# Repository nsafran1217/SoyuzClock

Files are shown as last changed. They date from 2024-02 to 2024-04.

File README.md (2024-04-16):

# SoyuzClock
Recreation of the 744H clock that flew on Soyuz space capsules

This is meant to be an accurate replica of the Soyuz 744H clock as feature on CuriousMarc's youtube channel.

- `SoyuzControlBoard` contains the KiCAD files for the esp32 board. There are many components that are optional.

- `SoyuzLedBoard` contains the KiCAD files for the board that the LED display mount on.

- `Soyuz-esp32` contains the PlatformIO project that runs the clock

## Part numbers
- АЛС324А is the 7 segment LED display. They are available on eBay or at tubes-store.com. They have the same quality issues as found in the real clock.

- МТ-1 is the toggle switch. They are available on eBay.

- ПКн2-1 is the correct push button, however, they are hard to find in the west. I found some stores selling them in Ukraine and Russia, but each switch is at least $15 US, plus you need to convince the seller its worth their time to ship it to you.

- KM1-1 is the next best option. They are easily found on eBay. The push button is smaller than the real switch. This is what I am using for now.

# 
Thanks to Curious Marc for documenting this clock: https://www.curiousmarc.com/space/soyuz-clock-744h-digital

I made a recreation of the case in FreeCAD based HEAVILY on this FreeCAD design: https://grabcad.com/library/soyuz-spacecraft-clock-1

This design will be added to this repo when finalized.

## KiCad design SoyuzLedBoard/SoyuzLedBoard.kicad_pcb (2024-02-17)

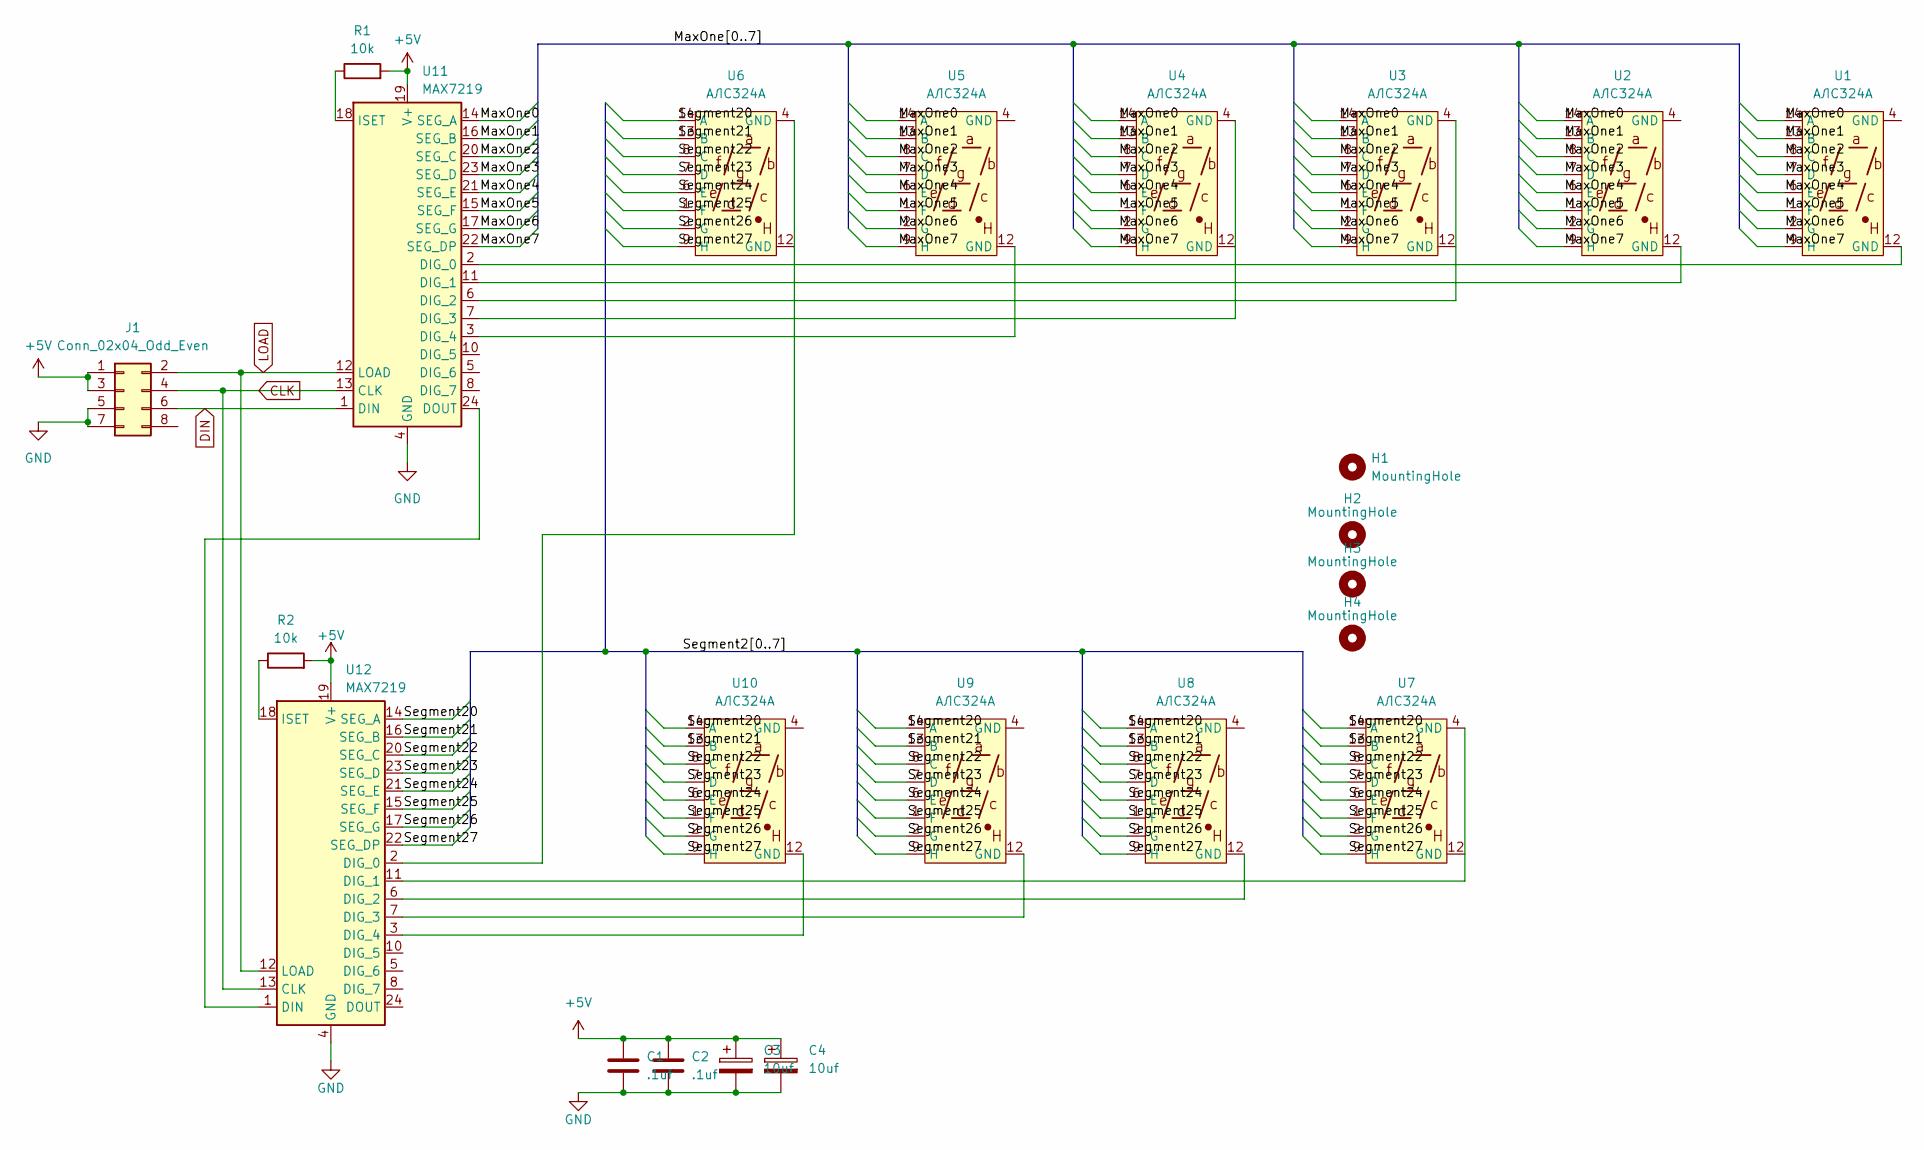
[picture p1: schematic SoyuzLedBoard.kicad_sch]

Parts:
C1, C2: .1uf; C_0805_2012Metric_Pad1.18x1.45mm_HandSolder
C3, C4: 10uf; CP_Radial_D4.0mm_P2.00mm
H1, H2, H3, H4: MountingHole; MountingHole_3.2mm_M3
J1: Conn_02x04_Odd_Even; PinHeader_2x04_P2.54mm_Vertical
R1, R2: 10k; R_0805_2012Metric_Pad1.20x1.40mm_HandSolder
U1, U2, U3, U4, U5, U6, U7, U8, U9, U10: АЛС324А; Metric-2.5mm DIP14
U11, U12: MAX7219; DIP-24_W7.62mm

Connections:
+5V: C1.1, C2.1, C3.1, C4.1, J1.1, J1.3, R1.2, R2.2, U11.19 (V+), U12.19 (V+)
/MaxOne0: U1.14 (A), U2.14 (A), U3.14 (A), U4.14 (A), U5.14 (A), U11.14 (SEG_A)
/MaxOne1: U1.13 (B), U2.13 (B), U3.13 (B), U4.13 (B), U5.13 (B), U11.16 (SEG_B)
/MaxOne2: U1.8 (C), U2.8 (C), U3.8 (C), U4.8 (C), U5.8 (C), U11.20 (SEG_C)
/MaxOne3: U1.7 (D), U2.7 (D), U3.7 (D), U4.7 (D), U5.7 (D), U11.23 (SEG_D)
/MaxOne4: U1.6 (E), U2.6 (E), U3.6 (E), U4.6 (E), U5.6 (E), U11.21 (SEG_E)
/MaxOne5: U1.1 (F), U2.1 (F), U3.1 (F), U4.1 (F), U5.1 (F), U11.15 (SEG_F)
/MaxOne6: U1.2 (G), U2.2 (G), U3.2 (G), U4.2 (G), U5.2 (G), U11.17 (SEG_G)
/MaxOne7: U1.9 (H), U2.9 (H), U3.9 (H), U4.9 (H), U5.9 (H), U11.22 (SEG_DP)
/Segment20: U6.14 (A), U7.14 (A), U8.14 (A), U9.14 (A), U10.14 (A), U12.14 (SEG_A)
/Segment21: U6.13 (B), U7.13 (B), U8.13 (B), U9.13 (B), U10.13 (B), U12.16 (SEG_B)
/Segment22: U6.8 (C), U7.8 (C), U8.8 (C), U9.8 (C), U10.8 (C), U12.20 (SEG_C)
/Segment23: U6.7 (D), U7.7 (D), U8.7 (D), U9.7 (D), U10.7 (D), U12.23 (SEG_D)
/Segment24: U6.6 (E), U7.6 (E), U8.6 (E), U9.6 (E), U10.6 (E), U12.21 (SEG_E)
/Segment25: U6.1 (F), U7.1 (F), U8.1 (F), U9.1 (F), U10.1 (F), U12.15 (SEG_F)
/Segment26: U6.2 (G), U7.2 (G), U8.2 (G), U9.2 (G), U10.2 (G), U12.17 (SEG_G)
/Segment27: U6.9 (H), U7.9 (H), U8.9 (H), U9.9 (H), U10.9 (H), U12.22 (SEG_DP)
CLK: J1.4, U11.13 (CLK), U12.13 (CLK)
DIN: J1.6, U11.1 (DIN)
GND: C1.2, C2.2, C3.2, C4.2, J1.5, J1.7, U11.4 (GND), U11.9 (GND), U12.4 (GND), U12.9 (GND)
LOAD: J1.2, U11.12 (LOAD), U12.12 (LOAD)
unnamed: U1.12 (GND), U11.2 (DIG_0)
unnamed: U2.12 (GND), U11.11 (DIG_1)
unnamed: U3.4 (GND), U11.6 (DIG_2)
unnamed: U4.4 (GND), U11.7 (DIG_3)
unnamed: U5.12 (GND), U11.3 (DIG_4)
unnamed: U11.24 (DOUT), U12.1 (DIN)
unnamed: R1.1, U11.18 (ISET)
unnamed: U6.4 (GND), U12.2 (DIG_0)
unnamed: U7.4 (GND), U12.11 (DIG_1)
unnamed: U8.12 (GND), U12.6 (DIG_2)
unnamed: U9.12 (GND), U12.7 (DIG_3)
unnamed: U10.12 (GND), U12.3 (DIG_4)
unnamed: R2.1, U12.18 (ISET)

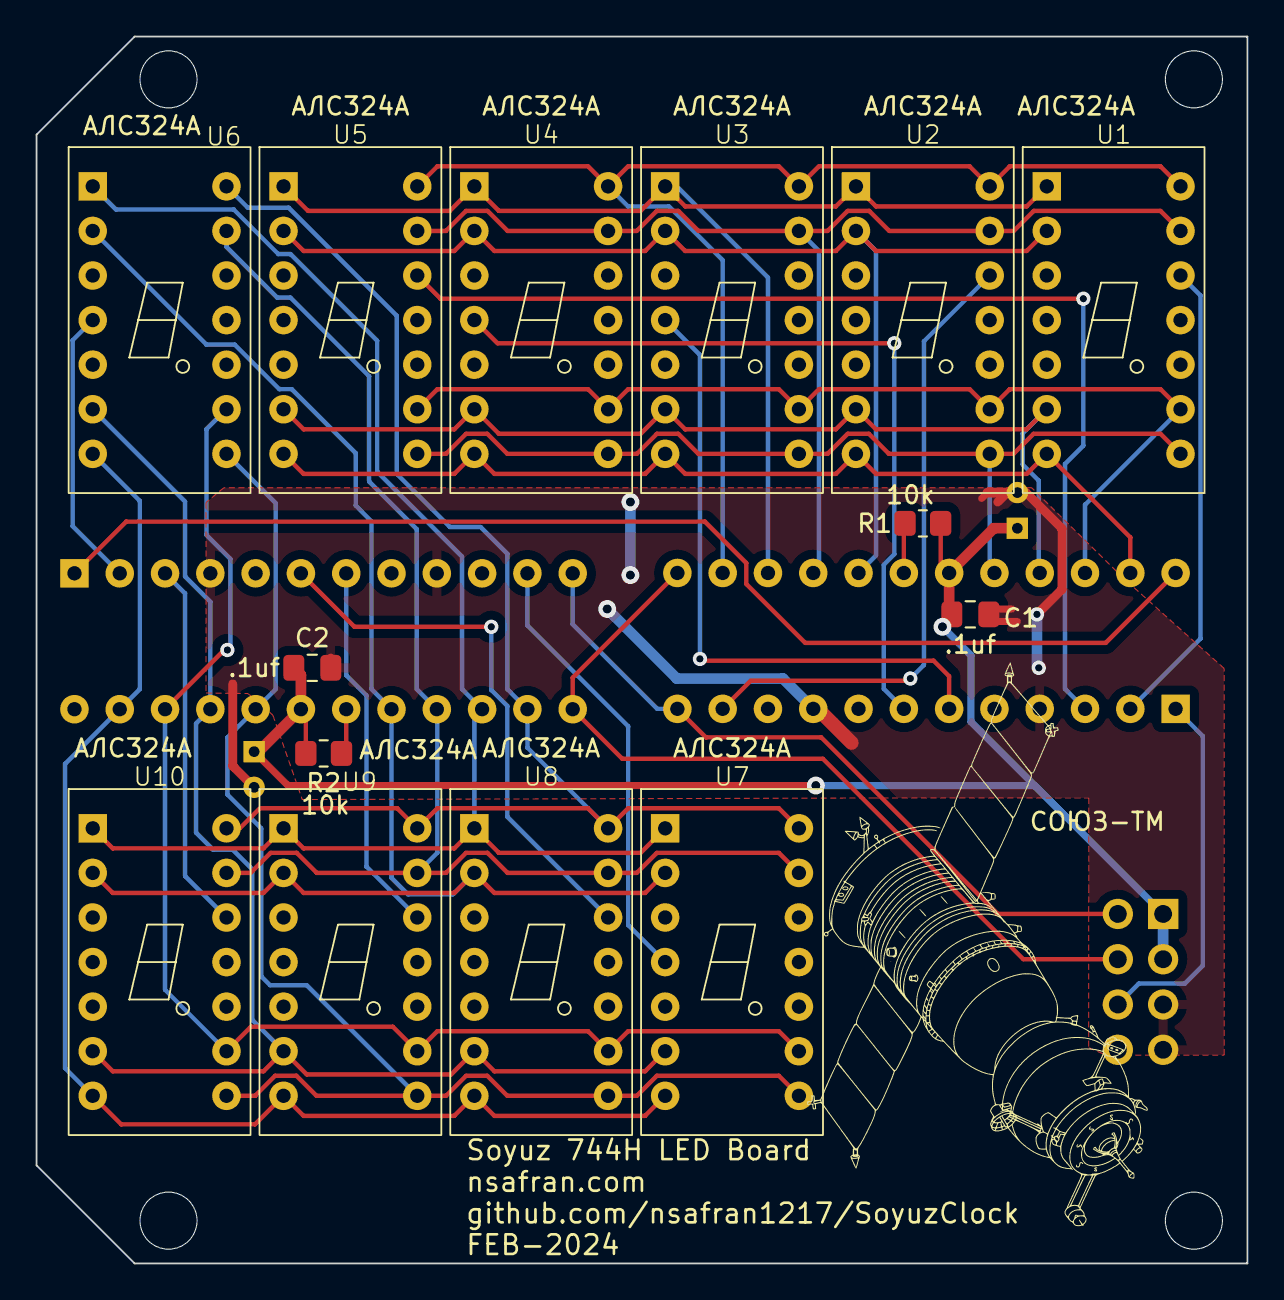
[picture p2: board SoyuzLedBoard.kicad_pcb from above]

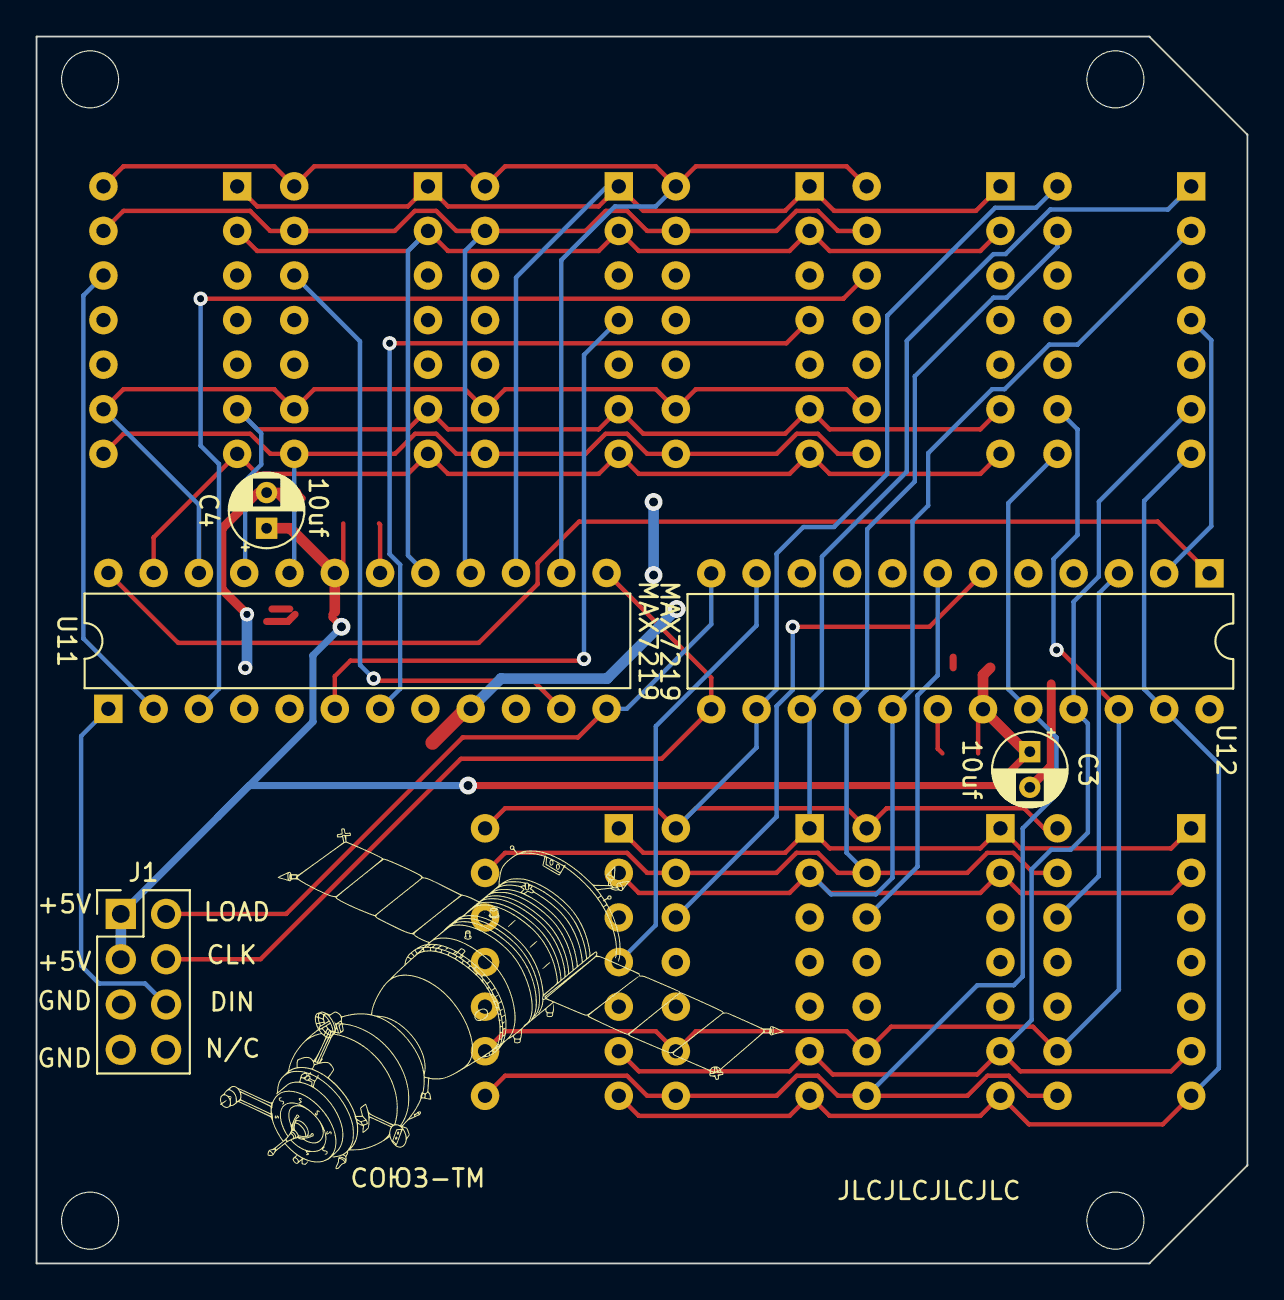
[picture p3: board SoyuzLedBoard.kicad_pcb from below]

Board: 2 copper layers, 67.9 x 68.8 mm, 23 parts (5 on the bottom side), 34 nets.

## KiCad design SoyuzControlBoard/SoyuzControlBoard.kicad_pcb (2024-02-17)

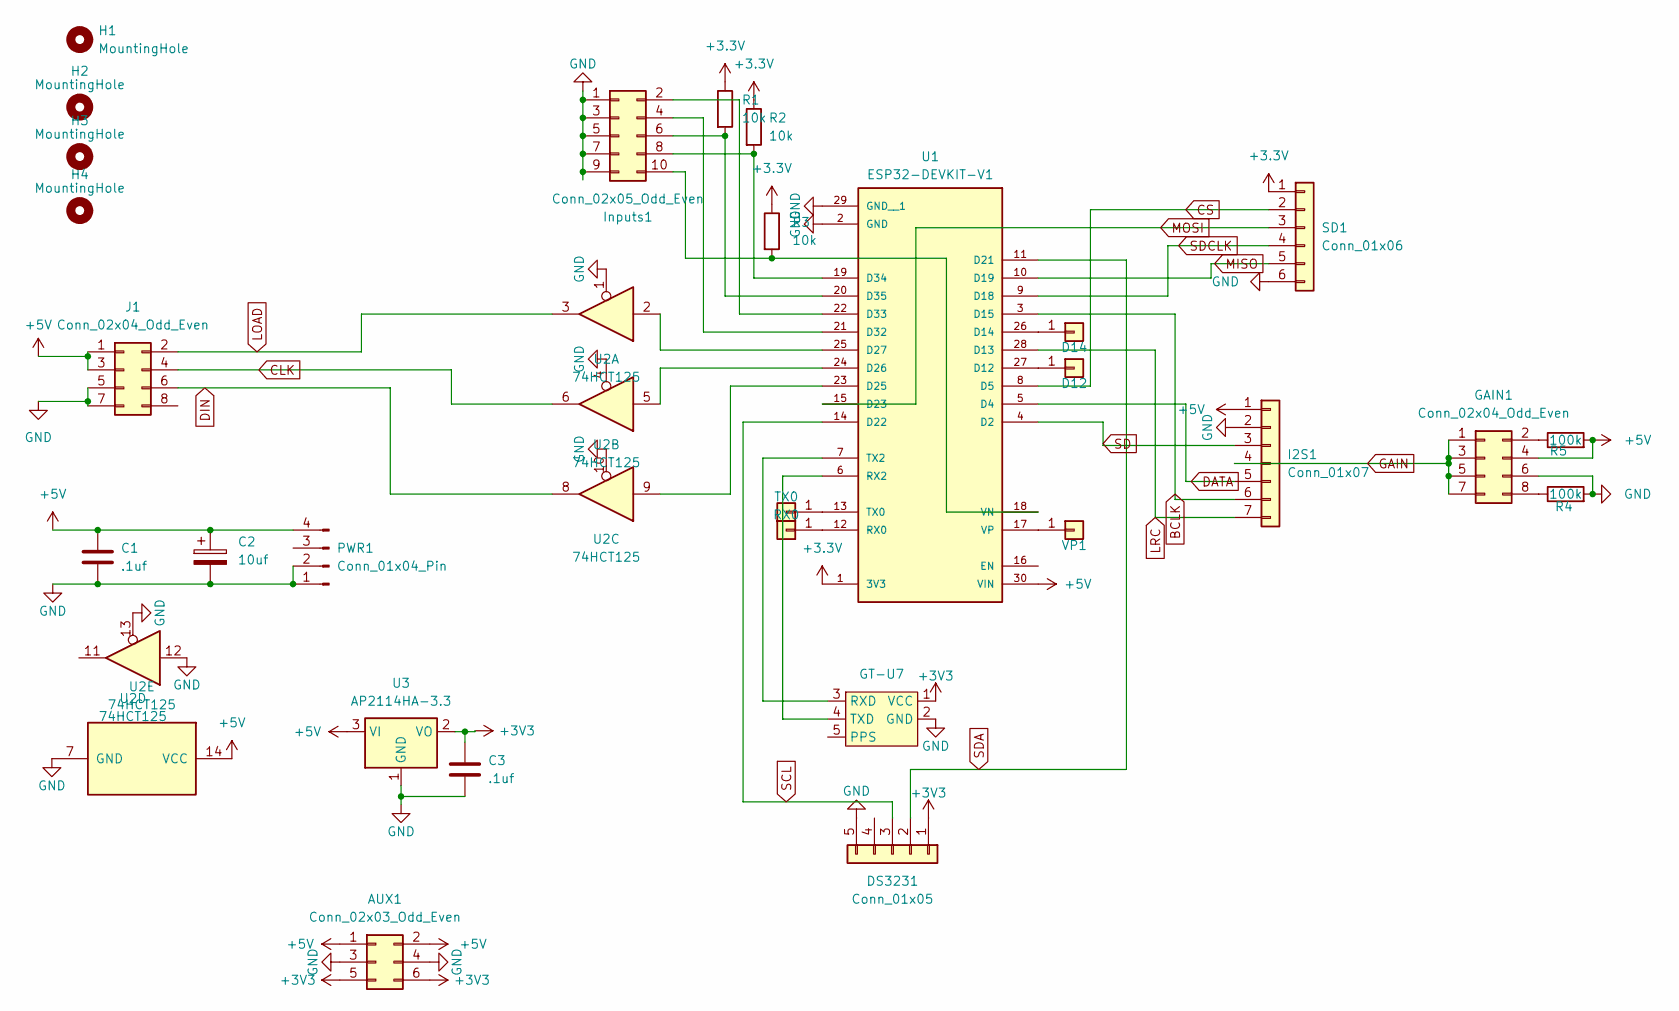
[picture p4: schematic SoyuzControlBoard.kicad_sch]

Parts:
AUX1: Conn_02x03_Odd_Even; PinHeader_2x03_P2.54mm_Vertical
C1, C3: .1uf; C_0805_2012Metric_Pad1.18x1.45mm_HandSolder
C2: 10uf; CP_Radial_D4.0mm_P2.00mm
D12, D14: Conn_01x01; 1x01
DS3231: Conn_01x05; PinHeader_1x05_P2.54mm_Vertical
GAIN1: Conn_02x04_Odd_Even; PinHeader_2x04_P2.54mm_Vertical
GT-U7: GT-U7_GPS
H1, H2, H3, H4: MountingHole; MountingHole_3.2mm_M3
I2S1: Conn_01x07; PinHeader_1x07_P2.54mm_Vertical
Inputs1: Conn_02x05_Odd_Even; IDC-Header_2x05_P2.54mm_Vertical
J1: Conn_02x04_Odd_Even; PinSocket_2x04_P2.54mm_Vertical
PWR1: Conn_01x04_Pin; PinHeader_1x04_P2.54mm_Vertical
R1, R2, R3: 10k; R_0805_2012Metric_Pad1.20x1.40mm_HandSolder
R4, R5: 100k; R_0805_2012Metric_Pad1.20x1.40mm_HandSolder
RX0: Conn_01x01; 1x01
SD1: Conn_01x06; PinHeader_1x06_P2.54mm_Vertical
TX0: Conn_01x01; 1x01
U1: ESP32-DEVKIT-V1; MODULE_ESP32_DEVKIT_V1; PARTREV N/A
U2: 74HCT125; DIP-14_W7.62mm
U3: AP2114HA-3.3; SOT-223-3_TabPin2
VP1: Conn_01x01; 1x01

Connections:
+3.3V: R1.1, R2.1, R3.1, SD1.1, U1.1 (3V3)
+3V3: AUX1.5, AUX1.6, C3.1, DS3231.1, GT-U7.1 (VCC), U3.2 (VO); also elsewhere on the board
+5V: AUX1.1, AUX1.2, C1.1, C2.1, GAIN1.4, I2S1.1, J1.1, J1.3, PWR1.4, R5.2, U1.30 (VIN), U2.14 (VCC), U3.3 (VI); also elsewhere on the board
BCLK: I2S1.6, U1.3 (D15)
CLK: J1.4, U2.6
CS: SD1.2, U1.8 (D5)
DATA: I2S1.5, U1.5 (D4)
DIN: J1.6, U2.8
GAIN: GAIN1.1, GAIN1.3, GAIN1.5, GAIN1.7, I2S1.4
GND: AUX1.3, AUX1.4, C1.2, C2.2, C3.2, DS3231.5, GAIN1.6, GT-U7.2 (GND), I2S1.2, Inputs1.1, Inputs1.3, Inputs1.5, Inputs1.7, Inputs1.9, J1.5, J1.7, PWR1.1, PWR1.2, R4.2, SD1.6, U1.2 (GND), U1.29 (GND__1), U2.1, U2.4, U2.7 (GND), U2.10, U2.12, U2.13, U3.1 (GND); also elsewhere on the board
LOAD: J1.2, U2.3
LRC: I2S1.7, U1.28 (D13)
MISO: SD1.5, U1.10 (D19)
MOSI: SD1.3, U1.15 (D23)
unnamed: D12.1, U1.27 (D12)
unnamed: D14.1, U1.26 (D14)
unnamed: GAIN1.2, R5.1
unnamed: GAIN1.8, R4.1
unnamed: GT-U7.3 (RXD), U1.7 (TX2)
unnamed: GT-U7.4 (TXD), U1.6 (RX2)
unnamed: Inputs1.2, U1.22 (D33)
unnamed: Inputs1.4, U1.21 (D32)
unnamed: Inputs1.6, R1.2, U1.20 (D35)
unnamed: Inputs1.8, R2.2, U1.19 (D34)
unnamed: Inputs1.10, R3.2, U1.18 (VN)
unnamed: RX0.1, U1.12 (RX0)
unnamed: TX0.1, U1.13 (TX0)
unnamed: U1.23 (D25), U2.9
unnamed: U1.24 (D26), U2.5
unnamed: U1.25 (D27), U2.2
unnamed: U1.17 (VP), VP1.1
SCL: DS3231.3, U1.14 (D22)
SD: I2S1.3, U1.4 (D2)
SDA: DS3231.2, U1.11 (D21)
SDCLK: SD1.4, U1.9 (D18)

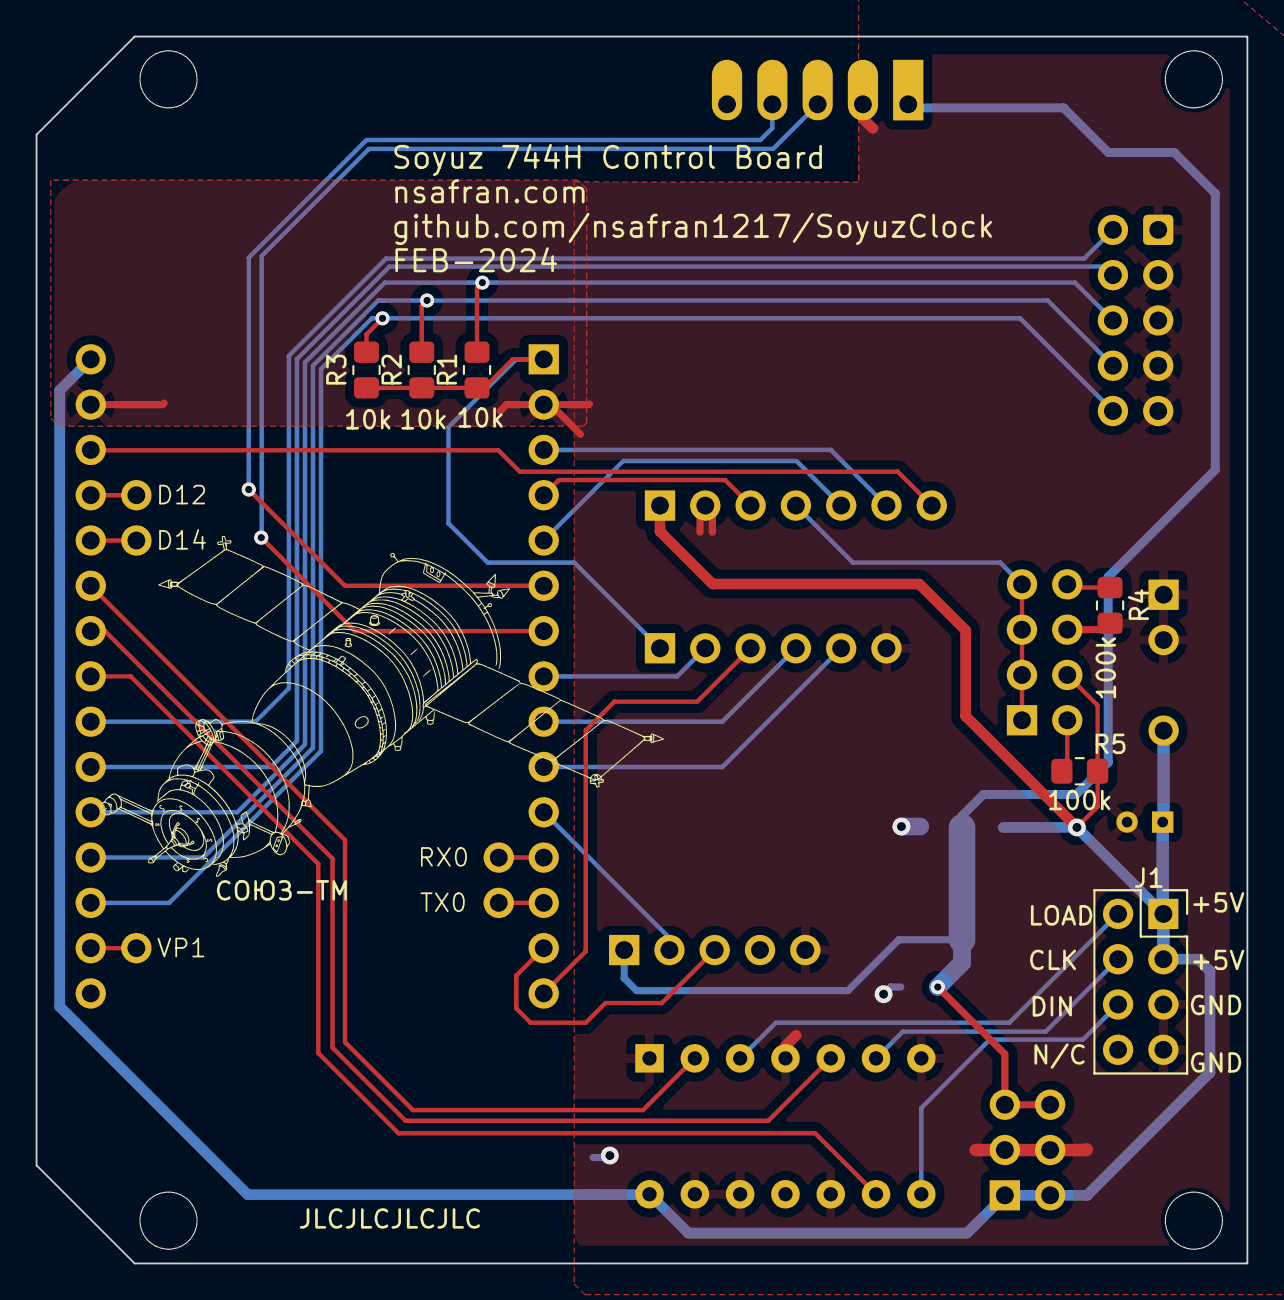
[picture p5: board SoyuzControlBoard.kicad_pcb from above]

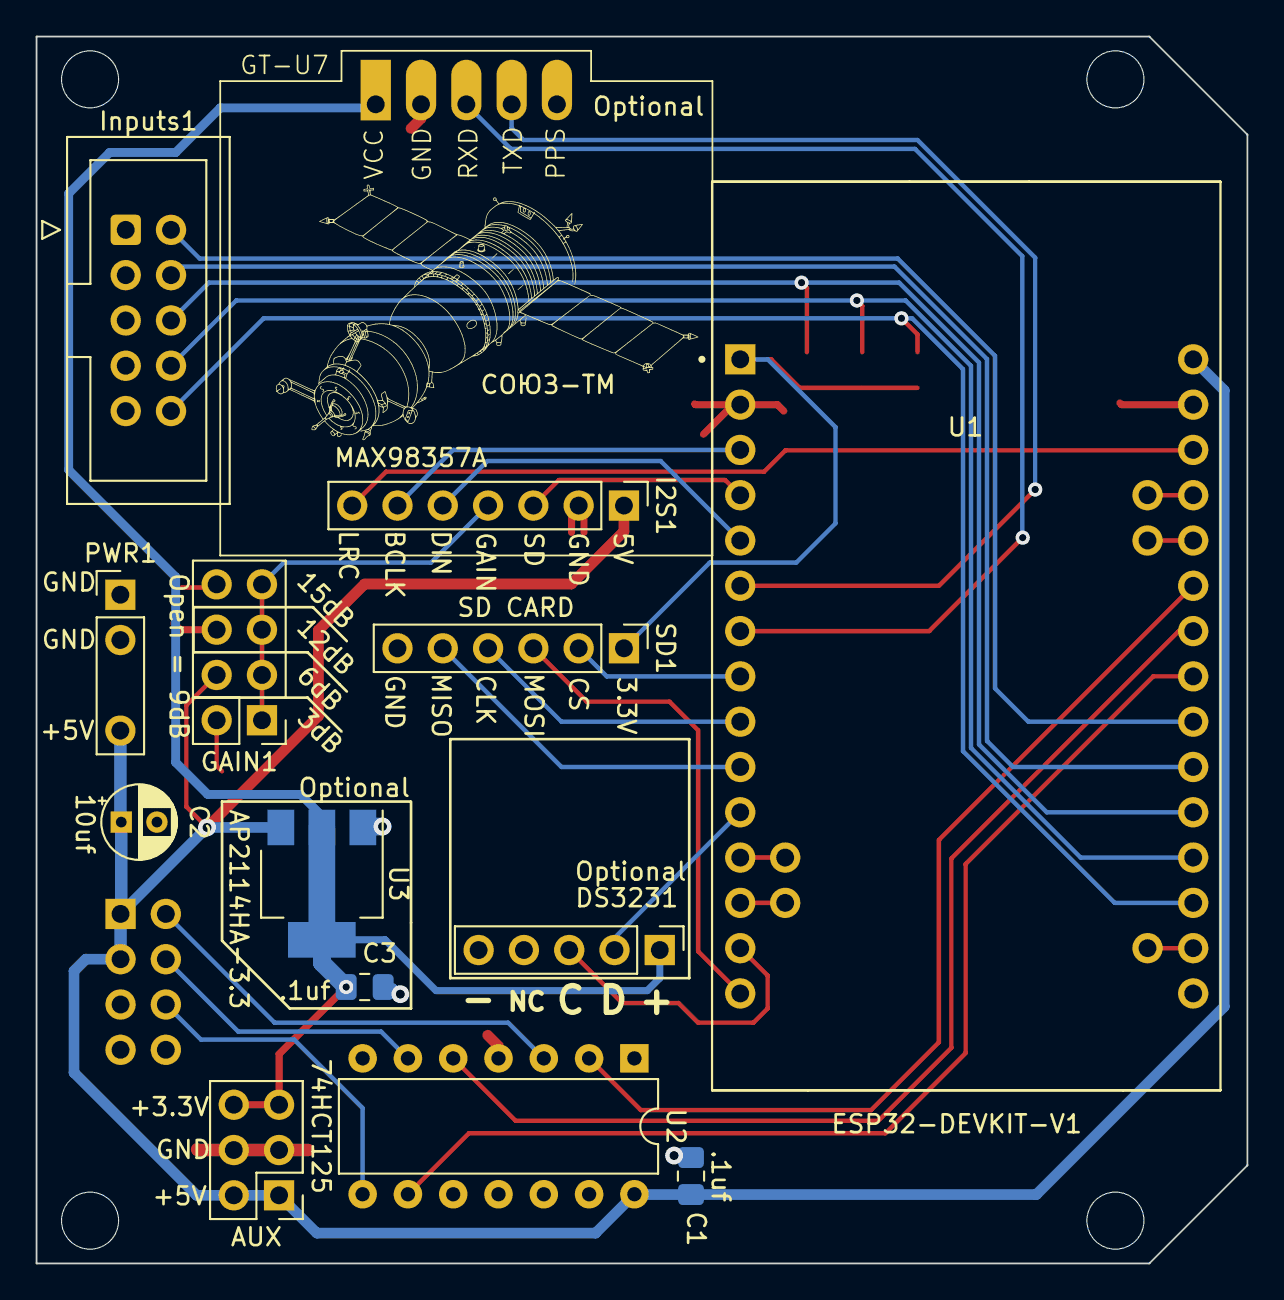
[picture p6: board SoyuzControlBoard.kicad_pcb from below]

Board: 2 copper layers, 67.9 x 68.8 mm, 29 parts (14 on the bottom side), 35 nets.

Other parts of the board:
AUX: Conn_02x03_Odd_Even; PinHeader_2x03_P2.54mm_Vertical

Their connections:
+3V3: AUX.5, AUX.6; also elsewhere on the board
+5V: AUX.1, AUX.2; also elsewhere on the board
GND: AUX.3, AUX.4; also elsewhere on the board

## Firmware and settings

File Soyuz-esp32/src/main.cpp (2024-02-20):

#include <Arduino.h>
#include <NTPClient.h>
#include <EEPROM.h>
#include <WiFi.h>
#include <time.h>

#include <SoyuzDisplay.h>

#ifdef ENABLE_SOUND
#include <SPI.h>
#include <SD.h>
#include "AudioTools.h"
#include "AudioCodecs/CodecMP3Helix.h"
#endif

#define ENABLE_WIFI

#ifdef ENABLE_WIFI
#include <WiFiManager.h>
#endif

// EEPROM ADDRESSES
#define EEPROM_CRC_ADDRESS 0
#define SETTINGS_ADDRESS 4

// pin definitions
#define MAX_DATA_PIN 25
#define MAX_CLK_PIN 26
#define MAX_LOAD_PIN 27

#define I2S_SD_PIN 2
#define I2S_DIN_PIN 4
#define I2S_BCLK_PIN 15
#define I2S_LRC_PIN 13

#define SD_CS_PIN 5

#define RTC_SCL_PIN 22
#define RTC_SDA_PIN 21

#define RUN_CORRECT_SW_PIN 39 // VN
#define OP_SW_PIN 34
#define ON_SW_PIN 35
#define START_STOP_BUT_PIN 33
#define ENTER_BUT_PIN 32

// Setup Devices
SoyuzDisplay display = SoyuzDisplay(MAX_DATA_PIN, MAX_CLK_PIN, MAX_LOAD_PIN);
#ifdef ENABLE_SOUND
// Audio and SD card
I2SStream i2s;                                           // final output of decoded stream
EncodedAudioStream decoder(&i2s, new MP3DecoderHelix()); // Decoding stream
StreamCopy copier;
File audioFile;
#endif

// Mutexs
const TickType_t delay500ms = pdMS_TO_TICKS(500);
// SemaphoreHandle_t timeChangedMutex;
SemaphoreHandle_t displayMutex;

// Global Vars
unsigned long lastButtonPress = 0;
// Not sure if this is the best way to do this
unsigned long refreshDateDisplayTimer = 0;
unsigned long refreshAlarmDisplayTimer = 0;
// DateTime Vars
uint8_t hour = 0, minute = 0, second = 0, month = 0, day = 0;
uint8_t alarmHour = 0, alarmMinute = 0, alarmSecond = 0;
uint8_t stopWatchMinute = 0, stopWatchSecond = 0;
int year = 0;
int timeDots = 0;
int lastsecond = -1;
int lastsecondTime = -1;
int lastsecondStopWatch = -1;

// Struct for clock user settings
struct DeviceSettings
{
  bool twelveHourMode; // used only in normal mode
  bool enableSoundOutput;
  char ntpServer[50];
  long gmtOffset_sec;
  int daylightOffset_sec;
  int normalModeAlarm[3];
  enum modes
  {
    emulationMode,
    normalMode
  };
  modes defualtMode;
  modes currentMode;
};
DeviceSettings settings;

DeviceSettings::modes clockMode; // are we emulating the real thing?
bool alarmEnable = false;
int stopWatchMode = 0; // 0 = reset, 1= start, 2=stop
bool stopWatchRunning = false;
bool timeChanged = false;

// FUNCTIONS
void emulationMode();
void normalMode();
boolean readButton(uint8_t pin);
void updateDateTimeTask(void *parameter);
void displayTime();
void displayDate();
void displayAlarm();
void stopWatchTask(void *parameter);
bool wifiManagerSetup(bool adhoc);

bool setTime(int time[]); // 1 we set time, 0 we exited without changing time

boolean isBetweenHours(int hour, int displayOffHour, int displayOn);
uint32_t calculateCRC(const DeviceSettings &settings);
bool readEEPROMWithCRC(DeviceSettings &settings);
void writeEEPROMWithCRC(const DeviceSettings &settings);
void initWiFi();

void setup()
{
  // setup input pins
  pinMode(RUN_CORRECT_SW_PIN, INPUT);
  pinMode(OP_SW_PIN, INPUT);
  pinMode(ON_SW_PIN, INPUT);
  pinMode(START_STOP_BUT_PIN, INPUT_PULLUP);
  pinMode(ENTER_BUT_PIN, INPUT_PULLUP);
  delay(50);
  Serial.begin(115200);
  Serial.println("ON");
  displayMutex = xSemaphoreCreateMutex();

  EEPROM.begin(128);
  bool settingsValid = readEEPROMWithCRC(settings);
  // bool settingsValid = false;
  Serial.println(settings.currentMode);
  Serial.println(settings.defualtMode);
  Serial.println(settings.twelveHourMode);
  Serial.println(settings.ntpServer);
  Serial.println(settings.gmtOffset_sec);
  Serial.println(settings.daylightOffset_sec);
  if (!settingsValid)
  {
    Serial.println("CRC BAD");
    settings.twelveHourMode = true;
    strcpy(settings.ntpServer, "pool.ntp.org");
    settings.gmtOffset_sec = -18000;
    settings.daylightOffset_sec = 3600;
    settings.currentMode = DeviceSettings::emulationMode;
    settings.defualtMode = DeviceSettings::emulationMode;
    settings.normalModeAlarm[0] = 0;
    settings.normalModeAlarm[1] = 0;
    settings.normalModeAlarm[2] = 0;

    writeEEPROMWithCRC(settings);
    EEPROM.commit();
  }
  else
  {
    Serial.println("CRC GOOD");
  }
  display.writeStringToDisplay("RESET SOYUZ ERR WIFI");
  display.writeSoyuz();

#ifdef ENABLE_WIFI
  unsigned long resetTime = millis();
  while (!digitalRead(ENTER_BUT_PIN))
  {
    delay(500);
    Serial.println("SET");
    display.writeStringToDisplay("SET");
    if (millis() > resetTime + 5000UL)
    {                         // if held down for 5 seconds
      wifiManagerSetup(true); // adhoc change settings
    }
  }

  // wifiManagerSetup(true);
  if (!wifiManagerSetup(false)) // if we fail to connect to wifi, fall back to emulation mode
  {
    settings.currentMode = DeviceSettings::emulationMode;
    display.writeStringToDisplay("FAIL  CONN");
    delay(5000);
  }
#endif
#ifndef ENABLE_WIFI
  settings.currentMode = DeviceSettings::emulationMode; // force emulation mode if wifi is not enabled
#endif

  settings.currentMode = DeviceSettings::normalMode;
  clockMode = settings.currentMode;

  if (settings.currentMode != settings.defualtMode) // we booted into a different mode at the request of the user
  {
    settings.currentMode = settings.defualtMode;
    writeEEPROMWithCRC(settings); // put it back to default
    Serial.println("Setting defualt mode back");
  }

  if (clockMode == DeviceSettings::emulationMode)
  {
    struct tm timeinfo;
    timeinfo.tm_hour = 0;
    timeinfo.tm_min = 0;
    timeinfo.tm_sec = 0;
    timeinfo.tm_year = 124; // 2024
    timeinfo.tm_mon = 0;
    timeinfo.tm_mday = 1; // Day 1 of January
    time_t t = mktime(&timeinfo);
    struct timeval tv = {.tv_sec = t};
    settimeofday(&tv, nullptr); // Set the system time
    timeDots = 1;
    delay(500);
    xTaskCreate(updateDateTimeTask, "updateDateTimeTask", 4096, NULL, 1, NULL);
  }
  else
  {
    configTime(settings.gmtOffset_sec, settings.daylightOffset_sec, settings.ntpServer);
    alarmHour = settings.normalModeAlarm[0];
    alarmMinute = settings.normalModeAlarm[1];
    alarmSecond = settings.normalModeAlarm[2];
    delay(500);
    xTaskCreate(updateDateTimeTask, "updateDateTimeTask", 4096, NULL, 1, NULL);
  }

// setCpuFrequencyMhz(80); // slow down for power savings
#ifdef ENABLE_SOUND
  // SD Card and audio stuff

  AudioLogger::instance().begin(Serial, AudioLogger::Info);

  // setup file
  SD.begin();
  audioFile = SD.open("/sound2.mp3");

  // setup i2s
  auto config = i2s.defaultConfig(TX_MODE);
  config.pin_bck = 15;
  config.pin_ws = 13;
  config.pin_data = 4;
  i2s.begin(config);
  pinMode(2, OUTPUT);

  // setup I2S based on sampling rate provided by decoder
  decoder.setNotifyAudioChange(i2s);
  decoder.begin();

  // begin copy
  copier.begin(decoder, audioFile);

#endif
}

void loop()
{
  // updateDateTime(); // update the time vars
  //   main logic loop
  //   so what do we need to do?
  //   well, we need to read 3 switches and execute the correct actions.
  //   in addition, we need to read 2 buttons and determine what action they take based on some of the switches
  //   we need to work on implementing the soyuz functionality, then implement extra functionality
  //   the function of the buttons should depend on the current mode, either emulation or normal
#ifdef ENABLE_SOUND
  if (!copier.copy())
  {
    stop();
  }
#endif
  if (digitalRead(ON_SW_PIN)) // BKL, On Off Switch, ON
  {
  }
  else // OFF
  {
  }

  if (digitalRead(RUN_CORRECT_SW_PIN)) // RUN
  {
    if (digitalRead(OP_SW_PIN)) // current time
    {
      displayTime();
    }
    else // OP
    {
      displayAlarm();
    }
  }
  else // CORRECTION
  {
    if (digitalRead(OP_SW_PIN)) // current time
    {
      if (clockMode == DeviceSettings::emulationMode) // if emulation, allow to set time
      {
        int timeArr[3] = {hour, minute, second};
        if (setTime(timeArr))
        {
          struct tm timeinfo;
          timeinfo.tm_hour = timeArr[0];
          timeinfo.tm_min = timeArr[1];
          timeinfo.tm_sec = timeArr[2];
          timeinfo.tm_year = 124; // 2024
          timeinfo.tm_mon = 0;
          timeinfo.tm_mday = 1; // Day 1 of January
          time_t t = mktime(&timeinfo);
          struct timeval tv = {.tv_sec = t};
          settimeofday(&tv, nullptr); // Set the system time
        }
      }
      else // normal mode, do nothing
      {
        // normal mode, decide what to do
      }
    }
    else // OP
    {
      int timeArr[3] = {alarmHour, alarmMinute, alarmSecond};
      if (setTime(timeArr))
      {
        alarmEnable = true; // alarm is not enabled until the alarm has been set
        alarmHour = timeArr[0];
        alarmMinute = timeArr[1];
        alarmSecond = timeArr[2];
        if (clockMode == DeviceSettings::normalMode) // if normal mode, set alarm in eeprom
        {
          settings.normalModeAlarm[0] = alarmHour;
          settings.normalModeAlarm[1] = alarmMinute;
          settings.normalModeAlarm[2] = alarmSecond;
          writeEEPROMWithCRC(settings);
          EEPROM.commit();
        }
      }
    }
  }
  // stop watch section. Mostly same between both modes
  if (stopWatchMode == 0 && clockMode == DeviceSettings::normalMode)
  {
    displayDate(); // otherwise, display the date
  }
  if (readButton(START_STOP_BUT_PIN)) // stop watch button pressed
  {
    stopWatchMode++;
    if (stopWatchMode > 2)
      stopWatchMode = 0;
    // do some cleanup when the mode changes
    switch (stopWatchMode)
    {
    case 0:                                           // reset
      if (clockMode == DeviceSettings::emulationMode) // if emulation, just blank display when reset
      {
        if (xSemaphoreTake(displayMutex, pdMS_TO_TICKS(5)))
        {
          display.blankSmallDisplay();
          xSemaphoreGive(displayMutex);
        }
      }
      break;
    case 1: // start
      if (!stopWatchRunning)
      {
        stopWatchRunning = true;
        stopWatchMinute = 0;
        stopWatchSecond = 0;
        xTaskCreate(stopWatchTask, "stopWatchTask", 4096, NULL, 1, NULL);
        // stop watch task runs in background
      }
      break;
    case 2: // stop
      // task checks this var. will stop when false
      stopWatchRunning = false;
      break;
    }
  }

  // alarm section
  if (alarmEnable)
  {
    if (alarmMinute == minute && alarmSecond == second)
    {
      // TODO: Trigger alarm
    }
  }
}
boolean readButton(uint8_t pin) // true if button pressed
{
  // Read the button state
  uint8_t btnState = digitalRead(pin);
  // If we detect LOW signal, button is pressed
  if (btnState == LOW)
  {
    // if 50ms have passed since last LOW pulse, it means that the
    // button has been pressed, released and pressed again
    if (millis() - lastButtonPress > 50)
    {
      lastButtonPress = millis();
      return true;
    }
    else
    {
      lastButtonPress = millis();
      return false;
    }
    // Remember last button press event
  }
  else
  {
    return false;
  }
}
void setVfdMatrixTransition()
{
  // uint8_t digits[3] = {settings.matrix_transition, 255, settings.vfd_transition};
  // uint8_t minValues[3] = {0, 0, 0};
  // uint8_t maxValues[3] = {INS1Matrix::num_enums - 1, 0, IV17::num_enums - 1};
  // userInputClock(digits, minValues, maxValues, ALLOFF);
  // settings.matrix_transition = (INS1Matrix::TransitionMode)digits[0];
  // settings.vfd_transition = (IV17::TransitionMode)digits[2];
  writeEEPROMWithCRC(settings);
}

void updateDateTimeTask(void *parameter)
{
  struct tm timeinfo;
  int i = 0;
  while (1)
  {
    i = 0;
    delay(10);
    while (!getLocalTime(&timeinfo))
    {
      i++;
      Serial.println("Failed to obtain time");
      if (i > 10)
      {
        esp_restart(); // just reboot and try again
      }
    }
    int newSecond = timeinfo.tm_sec;

    if (lastsecond != newSecond) // only call if time has changed
    {
      lastsecond = newSecond;
      hour = timeinfo.tm_hour;
      minute = timeinfo.tm_min;
      second = timeinfo.tm_sec;
      year = timeinfo.tm_year + 1900;
      month = timeinfo.tm_mon + 1;
      day = timeinfo.tm_mday;
    }
  }
}
void displayTime()
{

  if (lastsecondTime != second) // only call if time has changed
  {
    lastsecondTime = second;
    Serial.printf("%02d/%02d/%d %02d:%02d:%02d\n", month, day, year, hour, minute, second); // debug
    if (xSemaphoreTake(displayMutex, pdMS_TO_TICKS(5)))
    {
      display.writeTimeToDisplay(hour, minute, second, timeDots);
      xSemaphoreGive(displayMutex);
    }
  }
}
void displayDate()
{
  if (millis() > refreshDateDisplayTimer + 1000UL) // write display every second
  {
    refreshDateDisplayTimer = millis();
    if (xSemaphoreTake(displayMutex, pdMS_TO_TICKS(5)))
    {
      display.writeTimeToSmallDisplay(month, day, 0);
      xSemaphoreGive(displayMutex);
    }
    Serial.printf("%02d/%02d\n", month, day); // debug
  }
}

void displayAlarm()
{
  if (millis() > refreshAlarmDisplayTimer + 1000UL) // write display every second
  {
    refreshAlarmDisplayTimer = millis();
    if (xSemaphoreTake(displayMutex, pdMS_TO_TICKS(5)))
    {
      display.writeTimeToDisplay(alarmHour, alarmMinute, alarmSecond, timeDots);
      xSemaphoreGive(displayMutex);
    }
  }
}

// updates display for stop watch when second changes
// used in emulation mode only
void stopWatchTask(void *parameter)
{
  while (stopWatchRunning)
  {
    delay(10);
    if (lastsecondStopWatch != second) // only call if time has changed
    {
      lastsecondStopWatch = second;
      stopWatchSecond++;
      if (stopWatchSecond > 59)
      {
        stopWatchSecond = 0;
        stopWatchMinute++;
      }
      if (stopWatchMinute > 99)
        stopWatchMinute = 0;
      if (xSemaphoreTake(displayMutex, pdMS_TO_TICKS(5)))
      {
        display.writeTimeToSmallDisplay(stopWatchMinute, stopWatchSecond, 0);
        Serial.printf("              %02d:%02d\n", stopWatchMinute, stopWatchSecond);
        xSemaphoreGive(displayMutex);
      }
    }
  }
  vTaskDelete(NULL);
}

bool setTime(int time[])
{
  // Array to store current values for each field
  int currentValues[6] = {0};
  // max value of each field
  int maxVal[6] = {2, 9, 5, 9, 5, 9};

  // Variables to handle button press timing
  unsigned long pressStartTime = 0;
  bool buttonPressed = false;
  int fieldIndex = 0;
  unsigned long lastIncrementTime = 0; // Timer to control the increment rate
  bool didWeSetTime = false;

  while (fieldIndex < 6 && !digitalRead(RUN_CORRECT_SW_PIN)) // if move back to run mode, exit
  {
    // we continute display time until a button press is detected, then we stop
    if (!didWeSetTime)
    {
      if (digitalRead(OP_SW_PIN)) // current time
      {
        // updateDateTime();
        displayTime();
      }
      else // OP
      {
        displayAlarm();
      }
    }
    else
    {
      if (xSemaphoreTake(displayMutex, pdMS_TO_TICKS(5)))
      {
        display.writeTimeToDisplay(
            currentValues[0] * 10 + currentValues[1],
            currentValues[2] * 10 + currentValues[3],
            currentValues[4] * 10 + currentValues[5],
            timeDots);
        xSemaphoreGive(displayMutex);
      }
    }
    // Check if the button is pressed (with debouncing)
    if (digitalRead(ENTER_BUT_PIN) == LOW)
    {
      didWeSetTime = true; // if we press button, then the time is set on exit
      if (!buttonPressed)
      {
        // Button pressed for the first time
        pressStartTime = millis();
        buttonPressed = true;
        Serial.println("Button pressed");
      }
      else
      {

        // Check if it's time to increment the value
        // Wait for 1500ms before starting to increment values
        if (millis() - lastIncrementTime >= 1000 && millis() - pressStartTime >= 1500)
        {
          currentValues[fieldIndex]++;
          if (currentValues[fieldIndex] > maxVal[fieldIndex])
            currentValues[fieldIndex] = 0; // Wrap around if exceeding 9
          if (fieldIndex == 1 && currentValues[fieldIndex] > 3 && currentValues[0] == 2)
            currentValues[fieldIndex] = 0;
          Serial.printf("Field %d value: %d\n", fieldIndex, currentValues[fieldIndex]);
          lastIncrementTime = millis();

          if (xSemaphoreTake(displayMutex, pdMS_TO_TICKS(5)))
          {
            display.writeTimeToDisplay(
                currentValues[0] * 10 + currentValues[1],
                currentValues[2] * 10 + currentValues[3],
                currentValues[4] * 10 + currentValues[5],
                timeDots);
            xSemaphoreGive(displayMutex);
          }
        }
      }
    }
    else
    {
      // Button released
      if (buttonPressed)
      {
        // Button was pressed
        fieldIndex++;
        Serial.printf("Moving to field %d\n", fieldIndex);
        // Print current field being edited
        if (fieldIndex < 6)
          Serial.printf("Editing field %d\n", fieldIndex);

        buttonPressed = false;
      }
    }

    // Update the original time array
    int j = 0;
    for (int i = 0; i < 3; i++)
    {
      time[i] = currentValues[j] * 10 + currentValues[j + 1];
      j++;
      j++;
    }

    // Delay to prevent too fast changes
    delay(50);
  }
  // if still in correction
  while (!digitalRead(RUN_CORRECT_SW_PIN))
  {
    // TODO, something. for now just hold execution
  }

  return didWeSetTime;
}

bool isBetweenHours(int hour, int displayOffHour, int displayOnHour)
{
  // Check if the hour is greater than or equal to displayOffHour
  // and less than displayOnHour, taking into account the 24-hour clock.
  if (displayOffHour < displayOnHour)
  {
    return (hour >= displayOffHour && hour < displayOnHour);
  }
  else
  {
    // Handle the case when displayOnHour crosses midnight
    return (hour >= displayOffHour || hour < displayOnHour);
  }
}
uint32_t calculateCRC(const DeviceSettings &settings) // Calculate CRC32 (simple algorithm)
{
  uint32_t crc = 0;
  const uint8_t *data = reinterpret_cast<const uint8_t *>(&settings);
  int dataSize = sizeof(settings);

  for (int i = 0; i < dataSize; ++i)
  {
    crc ^= (uint32_t)data[i] << 24;
    for (int j = 0; j < 8; ++j)
    {
      if (crc & 0x80000000)
      {
        crc = (crc << 1) ^ 0x04C11DB7; // CRC-32 polynomial
      }
      else
      {
        crc <<= 1;
      }
    }
  }

  return crc;
}
bool readEEPROMWithCRC(DeviceSettings &settings) // Read EEPROM and verify CRC
{
  uint32_t storedCRC;
  EEPROM.get(EEPROM_CRC_ADDRESS, storedCRC);

  DeviceSettings tempSettings;
  EEPROM.get(SETTINGS_ADDRESS, tempSettings);

  if (storedCRC == calculateCRC(tempSettings))
  {
    settings = tempSettings;
    return true; // CRC matches, data is valid
  }
  else
  {
    return false;
  }
}
void writeEEPROMWithCRC(const DeviceSettings &settings) // Write EEPROM with CRC
{
  // Write settings to EEPROM
  EEPROM.put(SETTINGS_ADDRESS, settings);

  // Calculate CRC for the data in EEPROM
  uint32_t calculatedCRC = calculateCRC(settings);

  // Write CRC to EEPROM
  EEPROM.put(EEPROM_CRC_ADDRESS, calculatedCRC);
}

#ifdef ENABLE_WIFI
WiFiManager wm;
String getParam(String name)
{
  // read parameter from server, for customhmtl input
  String value;
  if (wm.server->hasArg(name))
  {
    value = wm.server->arg(name);
  }
  return value;
}

void saveParamCallback()
{

  Serial.println("[CALLBACK] saveParamCallback fired");
  Serial.printf("ntp: %s\n", getParam("ntp_server"));
  Serial.printf("Offset: %s\n", getParam("gmt_offset"));
  Serial.printf("Daylight: %s\n", getParam("daylightOffset"));

  Serial.println("defaultmode = " + getParam("defaultmode"));
  Serial.println("twelvehourmpde= " + getParam("twelveHourMode"));

  settings.twelveHourMode = ((char)getParam("twelveHourMode")[0] == '0');
  String ntpServerValue = getParam("ntp_server");
  if (!ntpServerValue.isEmpty())
  {
    ntpServerValue.toCharArray(settings.ntpServer, sizeof(settings.ntpServer));
  }
  settings.gmtOffset_sec = getParam("gmt_offset").toInt();
  settings.daylightOffset_sec = getParam("daylightOffset").toInt();
  settings.defualtMode = ((char)getParam("defaultmode")[0] == '0' ? DeviceSettings::emulationMode : DeviceSettings::normalMode);

  writeEEPROMWithCRC(settings);
  EEPROM.commit();
}
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
